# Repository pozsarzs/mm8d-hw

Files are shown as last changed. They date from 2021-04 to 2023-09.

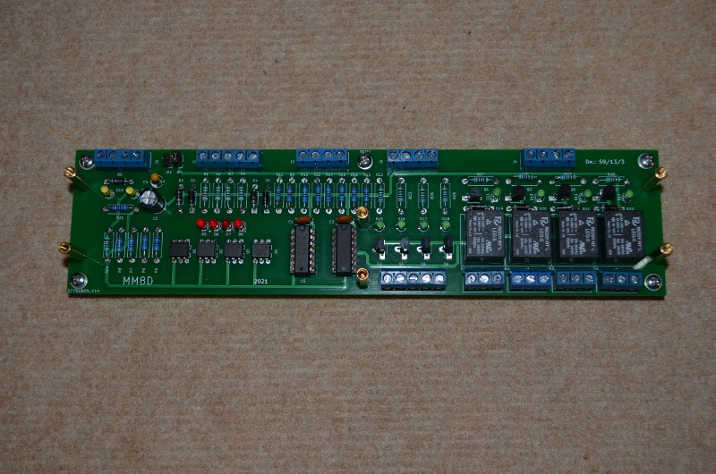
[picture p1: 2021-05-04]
pictures/mm8d.jpg

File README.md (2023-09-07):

**MM8D * Growing house and irrigation controlling and remote monitoring system**  
Copyright (C) 2020-2022 Pozsár Zsolt <pozsarzs@gmail.com>  
Homepage: <http://www.pozsarzs.hu>  
GitHub: <https://github.com/pozsarzs/mm8d-hw>

**Documentation**

- version:             2.0
- language:            en
- licence:             CC-BY-NC-4.0

**Hardware**

 - version:            v210326

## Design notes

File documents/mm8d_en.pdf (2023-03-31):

## MM8D Central controlling device

### Technical manual

Hardware version: v210326
MM8D software version: v0.3 Technical manual version: v2.0 Issue date: 2022.03.30.
Drawing number: 59/13/1
Titles: | MM8D Central controlling device | Rev.: 210326 Pages: | 1/26
| Technical manual
Name: Pozsár Zsolt | Date: | 2022.03.30.

Content

Titles: | MM8D Central controlling device | Rev.: 210326 Pages: | 2/26

## I. Hardware

Titles: | MM8D Central controlling device | Rev.: 210326 Pages: | 3/26

### 1. Technical data

Supply voltage: | 3.3/5 V DC SELV
Supply current: | max. 1 A
Isolation class: | Class 0
Mechanical size: | 240 x 60 x 25 mm
IP protection: | IP 00
Mass of cover: | termoplast (PC), only top cover

### 2. General description

The device consists of two parts: the control computer and the adapter card. The card can also be connected to 3.3V and 5V TTL systems. The control program is designed for PC and Raspberry Pi, the interface PC is connected to the LPT port, in the second case to the GPIO port. The adapter card has four 24V DC, galvanically isolated, polarity-protected inputs. Of the eight outputs, four are morse-contact relay outputs and four are open collector outputs for lower load (e.g., LED). The load capacity of the relay output is 5A (max. 240V AC or 100V DC), the load capacity of the open collector outputs is 80 mA (max. 24V DC).

### 3. Schematic and PCB drawings

The wiring diagrams of the device is shown in Annex 1, PCB drawings are in Annex 2-4. You can download it as part of the complete documentation or in separate PDF, SVG and KiCAD formats from the developer/manufacturer's website. The Gerber files needed for production are included in the package.

### 4. Other drawings and documents

Documentation package contents mechanical drawing of top cover.

### 5. Terms of use

Hardware documentation can be modified and/or redistributed under the Creativ Commons 4.0 Attribution Non-Commercial (CC-BY-NC-4.0) License. You can read the full text of the license online. (Refer to Chapter III for references.)

Titles: | MM8D Central controlling device | Rev.: 210326 Pages: | 4/26

### 6. Look of board

a) Manuals and connectors
1. LEDs of input #1-4
2. LEDs of relay output #1-4
3. LEDs of LED output #1-4
4. LEDs of power inputs
5. J1 connector - inputs
6. J2 connector - to computer
7. J3 connector - from power supply
8. J4 connector - from computer
9. J5 connector - from computer
10. J6 connector - contactors of relay output #1
11. J7 connector - contactors of relay output #2
12. J8 connector - contactors of relay output #3
13. J9 connector - contactors of relay output #4
14. J10 connector - LED outputs #1-4
15. Mounting holes
16. Jumpers

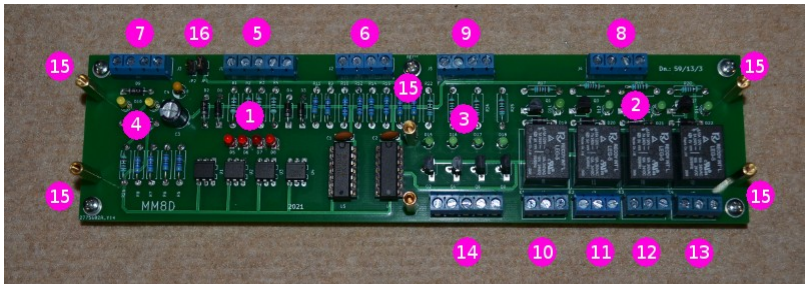
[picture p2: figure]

b) Jumpers
sign | function
for PC (LPT port) | for Rasperrry Pi (GPIO port)
JP1 | CLOSE | OPEN
JP2 | OPEN | CLOSE
Titles: | MM8D Central controlling device | Rev.: 210326 Pages: | 5/26

Figure 1: Manuals and connectors

c) Pinout of connectors
sign | pin | function | voltage level
J1 | 1 | input #1 | I1 | +24 V
| 2 | input #2 | I2 | +24 V
| 3 | input #3 | I3 | +24 V
| 4 | input #4 | I4 | +24 V
| 5 | common | ICOM
J2 | 1 | input #1 to computer | I1C | +3.3/5 V
| 2 | input #2 to computer | I2C | +3.3/5 V
| 3 | input #3 to computer | I3C | +3.3/5 V
| 4 | input #4 to computer | I4C | +3.3/5 V
J3 | 1 | power voltage input | +5 V | +5 V
| 2 | GND | GND
| 3 | GND | GND
| 4 | power voltage input | +3.3 V | +3.3 V
J4 | 1 | relay output #1 from computer | RO1C | +3.3/5 V
| 2 | relay output #2 from computer | RO2C | +3.3/5 V
| 3 | relay output #3 from computer | RO3C | +3.3/5 V
| 4 | relay output #4 from computer | RO4C | +3.3/5 V
J5 | 1 | LED output #1 from computer | LO1C | +3.3/5 V
| 2 | LED output #2 from computer | LO2C | +3.3/5 V
| 3 | LED output #3 from computer | LO3C | +3.3/5 V
| 4 | LED output #4 from computer | LO4C | +3.3/5 V
J6-9 | 1 | relay contactor NO | RO?NO
| 2 | relay contactor COM | RO?COM
| 3 | relay contactor NC | RO?NC
J10 | 1 | LED output #1 (open collector) | LO1
| 2 | LED output #2 (open collector) | LO2
| 3 | LED output #3 (open collector) | LO3
| 4 | LED output #4 (open collector) | LO4
| 5 | GND | GND
Titles: | MM8D Central controlling device | Rev.: 210326 Pages: | 6/26

d) Connect to computer
MM8D | Raspberry Pi | PC
sign | pin | function | sign | pin | function | sign | pin | function
J2 | 1 | I1C | | 3 | GPIO02 | LPT port | 15 | -ERROR
| 2 | I2C | | 5 | GPIO03 | | 13 | SELECT
| 3 | I3C | | 7 | GPIO04 | | 12 | PE
| 4 | I4C | | 11 | GPIO17 | | 10 | -ACK
J3 | 1 | +5 V | | 2 | +5 V | power supply | | +5 V
| 2 | GND | | 6 | GND | | | GND
| 3 | GND | | 9 | GND | LPT port | 25 | GND
| 4 | +3.3 V | | 17 | +3.3 V | | - | -
J4 | 1 | RO1C | | 12 | GPIO18 | | 2 | DO
| 2 | RO2C | | 16 | GPIO23 | | 3 | D1
| 3 | RO3C | | 18 | GPIO24 | | 4 | D2
| 4 | RO4C | | 22 | GPIO25 | | 5 | D3
J5 | 1 | LO1C | | 32 | GPIO12 | | 6 | D4
| 2 | LO2C | | 36 | GPIO16 | | 7 | D5
| 3 | LO3C | | 38 | GPIO20 | | 8 | D6
| 4 | LO4C | | 40 | GPIO21 | | 9 | D7

GPIO
port
e) Connect to environment
sign | pin | function | source/target
J1 | 1 | I1 | mains overcurrent breakers
| 2 | I2 | water pressure sensor (low pressure)
| 3 | I3 | water pressure sensor (high pressure)
| 4 | I4 | (unused)
| 5 | ICOM | common
J6 | 1-3 | RO1 | alarm output to alarm device
J7 | 1-3 | RO2 | valve control #1 of irrigator
J8 | 1-3 | RO3 | valve control #2 of irrigator
J9 | 1-3 | RO4 | valve control #3 of irrigator
J10 | 1 | LO1 | ACTIVE light (blue)
| 2 | LO2 | WARNING light (yellow)
| 3 | LO3 | ERROR light (red)
| 4 | LO4 | WATER PUMP ERROR light (red)
| 5 | GND | GND
Titles: | MM8D Central controlling device | Rev.: 210326 Pages: | 7/26

### 7. Downloadable documentation

The complete documentation of the hardware in the .tar.gz format compressed file can be downloaded from the manufacturer's website or Github. (Refer to Chapter III for references.) Name of package is: mm8d-hw-210326-2.0.tar.gz.

Content of package - only important files:

mm8d-hw
├───cad_files | KiCAD files
│ | mm8d.pro | project file
│ | mm8d.sch | schematic drawing
│ | mm8d.kicad_pcb | PCB drawing
│ | mm8d.drl | drilling file
│ | mm8d-*.gbr | Gerber files
├───documents | documentation
│ | mm8d_en.pdf | Technical manual
│ | pcb_*.pdf | pcb drawings
│ | sch_*.pdf | schematic drawings
├───pictures | pictures
│ | mm8d.jpg | look of the unit
│ | pcb_*.svg | PCB drawings
│ | sch_*.svg | schematic drawings
│
├───LICENCE | terms of use
└───README.md | short description
Titles: | MM8D Central controlling device | Rev.: 210326 Pages: | 8/26

## II. Software

Titles: | MM8D Central controlling device | Rev.: 210326 Pages: | 9/26

### 1. General description

The software consists of five main parts:

Operating daemon

The connected MM6D and MM7D electrical equipment is controlled by a Python program that runs as a service in the background. Utilities are Bash shell programs, configuration files are in text (INI) format. The configuration program has a full screen character interface, its source code (FreePascal) is only included in the tar.gz package. This part of the software is included in the tar.gz and mm8d-sw Debian packages.

Environmental characteristics adjustment program

The setup program has a full screen character interface, its source code (FreePascal) is included in the tar.gz package only. This part of the software is included in the tar.gz package and the mm8d-eec Debian package.

Web interface

Data access is provided by CGI programs written in Perl, its Bash shell utility, and web content consists of static HTML files. This requires an Apache2 web server. This part of the software is included in the tar.gz package and the mm8d-web Debian package.

Hardware checker program

This Python program can be used to verify that the hardware is working properly. Before testing running service of the software must be stopped. This part of the software is included in the tar.gz package and the mm8d-sw Debian package.

### 2. Prepare installation

Before installing the program, you need to install Raspbian OS Lite on your Raspberry Pi and Debian GNU/Linux on PC. Remember to change the default password for user pi, set the device name (hostname) and access to the local network. For easy remote access, use a permanent IP address or set up an IP address assignment on your router.

Prepare operation system:

user@localhost$ sudo apt-get update
user@localhost$ sudo apt-get upgrade
Titles: | MM8D Central controlling device | Rev.: 210326 Pages: | 10/26

user@localhost$ sudo apt-get install git wget
user@localhost$ sudo echo "deb http://www.szerafingomba.hu/deb/ ./" >> /etc/apt/sources.list
user@localhost$ sudo wget -q -O - http://www.szerafingomba.hu/deb/KEY.gpg | apt-key add -
user@localhost$ sudo apt-get update
user@localhost$ mkdir $HOME/download

### 3. Download

Download program from homepage:

user@localhost$ cd $HOME/download
user@localhost$ wget http://www.szerafingomba.hu/softwares/mm8d/mm8d-sw-0.3-armhf.tar.gz user@localhost$ tar -xzf mm8d-sw-0.3-armhf.tar.gz
(Note: on PC use amd64 or i386 instead armhf.)

Download latest version of program from Github:

user@localhost$ cd $HOME/download
user@localhost$ git clone http://github.com/pozsarzs/mm8d-sw.git

### 4. Installation

user@localhost$ cd mm8d-sw user@localhost$ ./prepare
user@localhost$ ./install

Download and install with package manager:

user@localhost$ sudo apt-get install mm8d-sw mm8d-web mm8d-eec

### 5. Files of program

The program's installed and runtime created files, with explanations of important files for the user and the purpose of symbolic links:

/
│
├───etc
│ | ├───cron.d
│ | │ | mm8d-sw
│ | │ | mm8d-web
│ | ├───init.d
│ | │ | mm8d.sh
│ | ├───rc0.d
│ | │ | K01mm8d.sh | » /etc/init.d/mm8d.sh
│ | ├───rc2.d
│ | │ | S01mm8d.sh | » /etc/init.d/mm8d.sh
│ | ├───rc3.d
│ | │ | S01mm8d.sh | » /etc/init.d/mm8d.sh
│ | ├───rc4.d
│ | │ | S01mm8d.sh | » /etc/init.d/mm8d.sh
│ | ├───rc5.d
│ | │ | S01mm8d.sh | » /etc/init.d/mm8d.sh
│ | ├───rc6.d
Titles: | MM8D Central controlling device | Rev.: 210326 Pages: | 11/26

│ | │ | K01mm8d.sh | » /etc/init.d/mm8d.sh
│ | ├───systemd
│ | │ | └───system
│ | │ | mm8d.service
│ | └───motd
├───usr
│ | ├───lib
│ | │ | └───cgi
│ | │ | getdata.cgi | CGI programs
│ | │ | getenvirconf.cgi
│ | │ | getpage.cgi
│ | └───local
│ | ├───bin
│ | │ | mm8d.py | daemon program
│ | │ | mm8d-creatediagrams | diagram creator
│ | │ | mm8d-editenvirconf | edit envir. characteristics
│ | │ | mm8d-editenvirconf.bin | settings editor
│ | │ | mm8d-editirrconf.bin | settings editor
│ | │ | mm8d-editmainconf | edit program settings
│ | │ | mm8d-editmainconf.bin | settings editor
│ | │ | mm8d-getsnapshots | camera picture downloader
│ | │ | mm8d-hwtest.py | hardware checker
│ | │ | mm8d-maintainlog | maintain log
│ | │ | mm8d-override | override outputs
│ | │ | mm8d-override.bin | override program
│ | │ | mm8d-startdaemon | start daemon
│ | │ | mm8d-statusofdaemon | show status of daemon
│ | │ | mm8d-stopdaemon | stop daemon
│ | │ | mm8d-updatestartpage | update startpage
│ | │ | mm8d-viewlog | show logfile
│ | │ | mm8d-webpage | show web interface
│ | ├───etc
│ | │ | └───mm8d
│ | │ | envir-ch?.ini | envir. characteristics settings
│ | │ | irrigator.ini | irrigator settings
│ | │ | mm8d.ini | program settings
│ | └───share
│ | ├───doc
│ | │ | └───mm8d
│ | │ | AUTHORS | author(s)
│ | │ | COPYING | terms of use (EN)
│ | │ | INSTALL.pc | installation instruction
│ | │ | INSTALL.raspi | installation instruction
│ | │ | README | information (EN)
│ | │ | VERSION | version
│ | │ | cgiprogs.txt | about CGI programs
│ | │ | changelog | log of changes
│ | │ | connecting.txt | about connecting device
│ | │ | copyright | copyright information
│ | │ | exitcodes.txt | about exit codes
│ | │ | logfiles.txt | about logfiles
│ | ├───locale
│ | │ | └───??
│ | │ | mm8d.msg | message files
│ | ├───man
│ | │ | ├───man1 | manual pages (EN)
│ | │ | │ mm8d-creatediagrams.1.gz
│ | │ | │ mm8d-editenvirconf.1.gz
│ | │ | │ mm8d-editmainconf.1.gz
│ | │ | │ mm8d-getsnapshots.1.gz
│ | │ | │ mm8d-hwtest.py.1.gz
│ | │ | │ mm8d-maintainlog.1.gz
Titles: | MM8D Central controlling device | Rev.: 210326 Pages: | 12/26

│ | │ | │ mm8d-override.1.gz
│ | │ | │ mm8d-startdaemon.1.gz
│ | │ | │ mm8d-statusofdaemon.1.gz
│ | │ | │ mm8d-stopdaemon.1.gz
│ | │ | │ mm8d-updatestartpage.1.gz
│ | │ | │ mm8d-viewlog.1.gz
│ | │ | │ mm8d-webpage.1.gz
│ | │ | ├───man7 | manual pages (EN)
│ | │ | │ getdata.cgi.7.gz
│ | │ | │ getenvirconf.cgi.7.gz
│ | │ | │ getpage.cgi.7.gz
│ | │ | └───man8 | manual pages (EN)
│ | │ | mm8d.py.8.gz
│ | └───mm8d
│ | footer_??.html
│ | header_??.html
└───var
├───local
│ | ├───lib
│ | │ | └───mm8d
│ | │ | └───?
│ | │ | out1
│ | │ | out2
│ | │ | out3
│ | │ | out4
│ | ├───lock
│ | │ | mm8d.lock
│ | │
│ | └───log
│ | mm8d-ch?.bak
│ | mm8d-ch?.log | log files
│ | debug-*.log | debug log
├───run
│ mm8d.pid
└───www
└───html
├───diagrams
│ | gasconcentrate-ch?.png
│ | humidity-ch?.png
│ | temperature-ch?.png
├───pics
│ | ants.jpg
│ | gasconcentrate-empty.png
│ | humidity-empty.png
│ | szerafin.ico
│ | temperature-empty.png
├───snapshots
│ | camera-ch?.jpg
styles.css
index.html
When installing with package manager, the program is installed to /usr instead of /usr/local.

### 6. Setup

Both configuration shell programs will stop the running service of MM8D, then open the editor and then start them after closing.
To set the program:

user@locahost$ mm8d-editmainconf

Titles: | MM8D Central controlling device | Rev.: 210326 Pages: | 13/26

To set the environmental characteristic and irrigator settings:

user@locahost$ mm8d-editenvirconf

### 7. Using the device

The device operates automatically after installation and setup and does not require any human intervention. The status of the growing site can be checked with a web browser, and settings can be made by logging via LAN with SSH client.

### 8. Terms of use

These programs are free softwares: you can redistribute they and/or modify they under the terms of the European Union Public License 1.1 version.

These programs are distributed in the hope that they will be useful, but WITHOUT ANY WARRANTY; without even the implied warranty of MERCHANTABILITY or FITNESS FOR A PARTICULAR PURPOSE. You can read the full text of the license online. (Refer to Chapter III for references.)

### 9. Screenshots

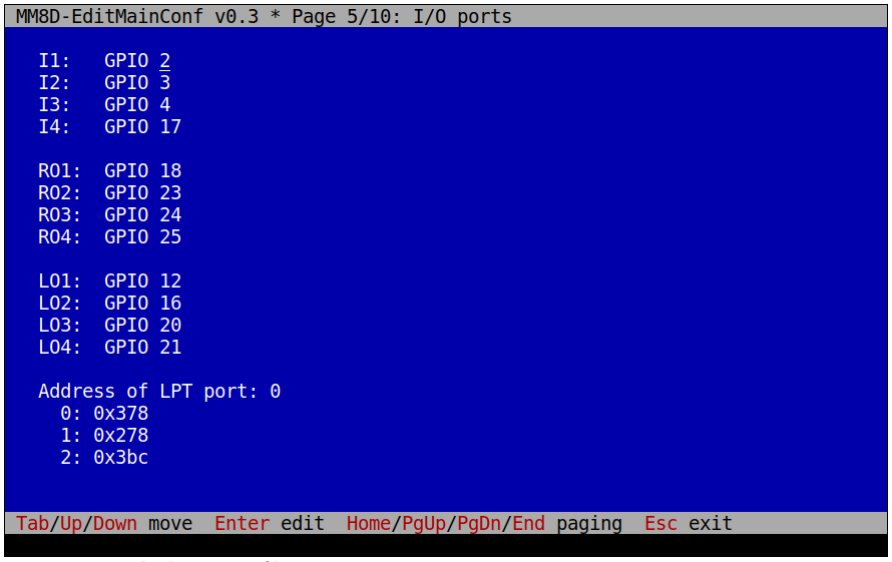
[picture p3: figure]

Titles: | MM8D Central controlling device | Rev.: 210326 Pages: | 14/26

Figure 2: mm8d-editmainconf.bin

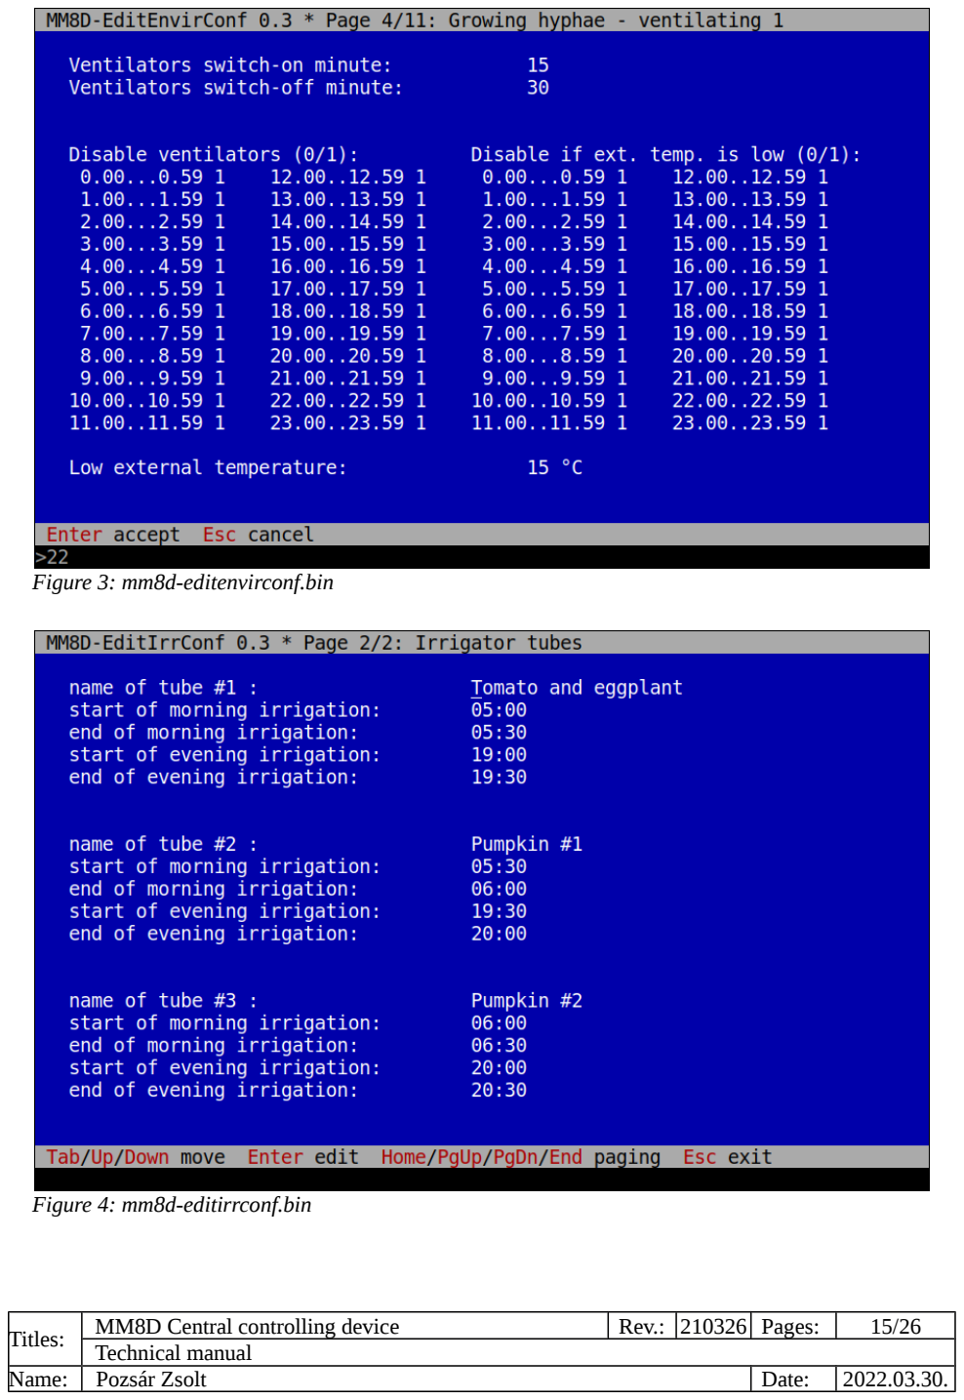
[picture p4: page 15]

Titles: | MM8D Central controlling device | Rev.: 210326 Pages: | 15/26

Figure 3: mm8d-editenvirconf.bin

Figure 4: mm8d-editirrconf.bin

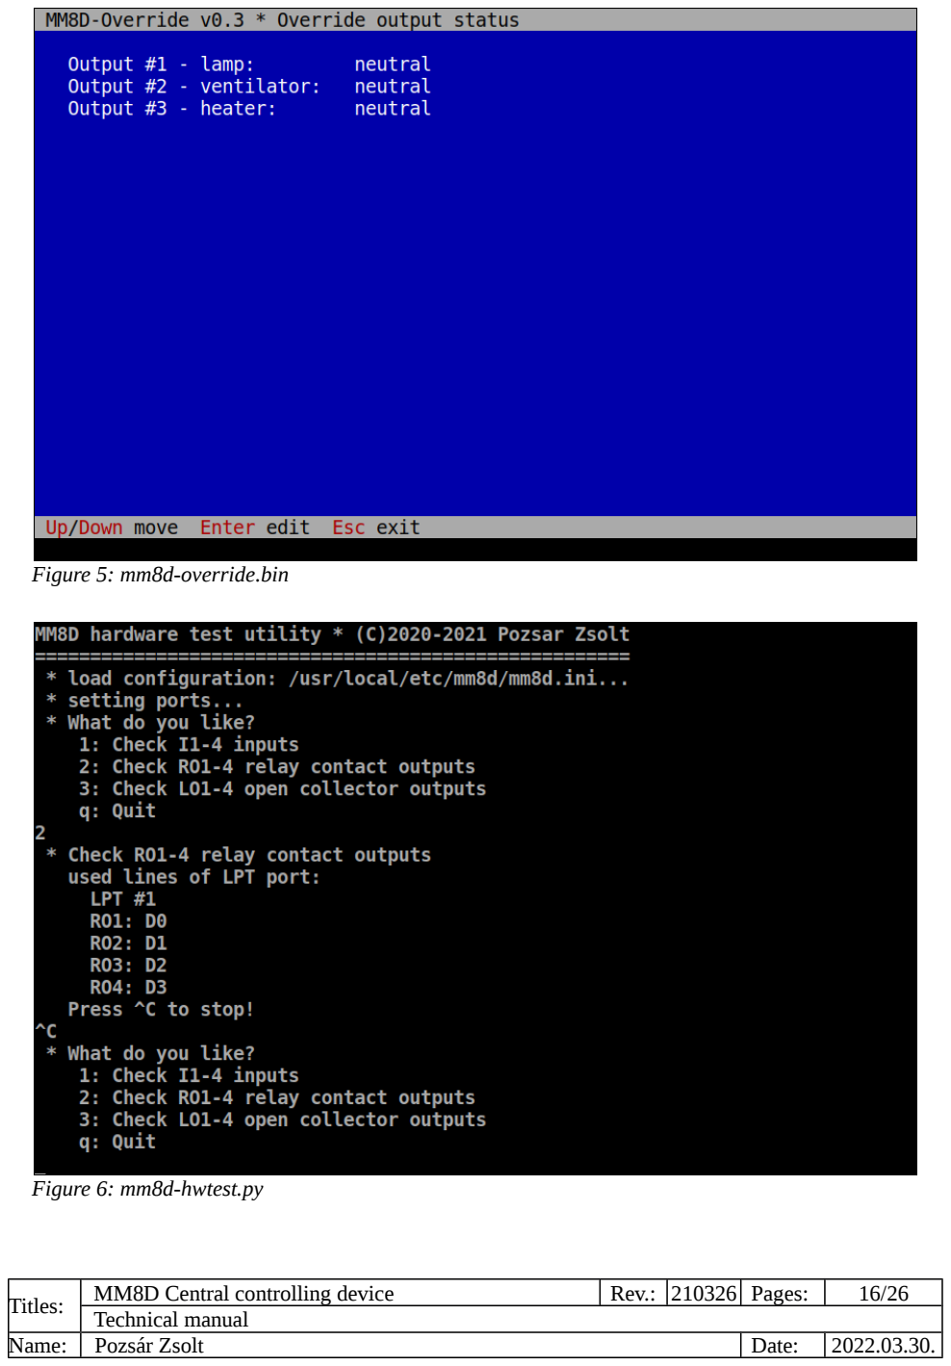
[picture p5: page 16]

Titles: | MM8D Central controlling device | Rev.: 210326 Pages: | 16/26

Figure 5: mm8d-override.bin

Figure 6: mm8d-hwtest.py

### 10. Downloadable software package

The software package in .tar.gz format compressed file can be downloaded from the manufacturer's website or Github. (Refer to Chapter III for references.)

Name of package are:mm8d-sw-0.3-amd64.tar.gz, mm8d-sw-0.3-armhf.tar.gz and mm8d-sw-0.3-i386.tar.gz.

Content of package - only important files:

mm8d-sw
│
├───binary | binary files
├───documents | documentation (EN)
│ | AUTHORS | author(s)
│ | INSTALL.pc | installation instruction
│ | INSTALL.raspi | installation instruction
│ | README | information
│ | VERSION | version number
│ | cgiprogs.txt | about CGI programs
│ | changelog | log of changes
│ | connecting.txt | about connecting device
│ | copyright | copyright information
│ | exitcodes.txt | about exit codes
│ | logfiles.txt | about logfiles
├───manuals | manual pages (EN)
├───messages | translated webpage text
├───packaging | files for make deb packages
├───programs | main programs (Python)
├───scripts | utility programs (Bash)
├───settings | configuration files
├───source | source code
├───webpage | static | components of webpage
├───install | installer script
├───prepare | system preparer script
├───uninstall | uninstaller script
├───LICENCE | terms of use (EN)
└───README.md | short description (EN)
Titles: | MM8D Central controlling device | Rev.: 210326 Pages: | 17/26

## III. Related links

Titles: | MM8D Central controlling device | Rev.: 210326 Pages: | 18/26

### 1. Hardware

Full package | http://www.szerafingomba.hu/equipments/mm8d/mm8d-hw-210326-2.0.tar.gz

Download from Github https://github.com/pozsarzs/mm8d-hw.git

Technical manual http://www.szerafingomba.hu/equipments/mm8d/technical-manual-210326-0.3-2.0-en.pdf

Schematic and PCB drawings (PDF):

Schematics | http://www.szerafingomba.hu/equipments/mm8d/sch_mm8d.pdf
PCB solder side | http://www.szerafingomba.hu/equipments/mm8d/pcb_mm8d-sold.pdf
PCB component side | http://www.szerafingomba.hu/equipments/mm8d/pcb_mm8d-comp.pdf
PCB silkscreen | http://www.szerafingomba.hu/equipments/mm8d/pcb_mm8d-silk.pdf

### 2. Software

for Raspberry Pi | http://www.szerafingomba.hu/softwares/mm8d/mm8d-sw-0.3-armhf.tar.gz
for AMD64 PC | http://www.szerafingomba.hu/softwares/mm8d/mm8d-sw-0.3-amd64.tar.gz
for i586 PC | http://www.szerafingomba.hu/softwares/mm8d/mm8d-sw-0.3-i586.tar.gz

Download from Github https://github.com/pozsarzs/mm8d-sw.git

### 3. Terms of use

CC-BY-NC-4.0 | https://creativecommons.org/licenses/by-nc/4.0/legalcode
CC-BY-NC-4.0 | https://creativecommons.org/licenses/by-nc/4.0/
EUPL v1.2 | https://eupl.eu/1.2/en/
GNU GPL v3.0 | https://www.gnu.org/licenses/gpl-3.0.html

### 4. Developer and manufacturer

Homepage | http://www.szerafingomba.hu
E-mail | info@szerafingomba.hu
Titles: | MM8D Central controlling device | Rev.: 210326 Pages: | 19/26

## IV. Annexes

Titles: | MM8D Central controlling device | Rev.: 210326 Pages: | 20/26

Content

1. Schematic of printed circuit board
2. PCB solder side
3. PCB component side
4. PCB silkscren
Titles: | MM8D Central controlling device | Rev.: 210326 Pages: | 21/26

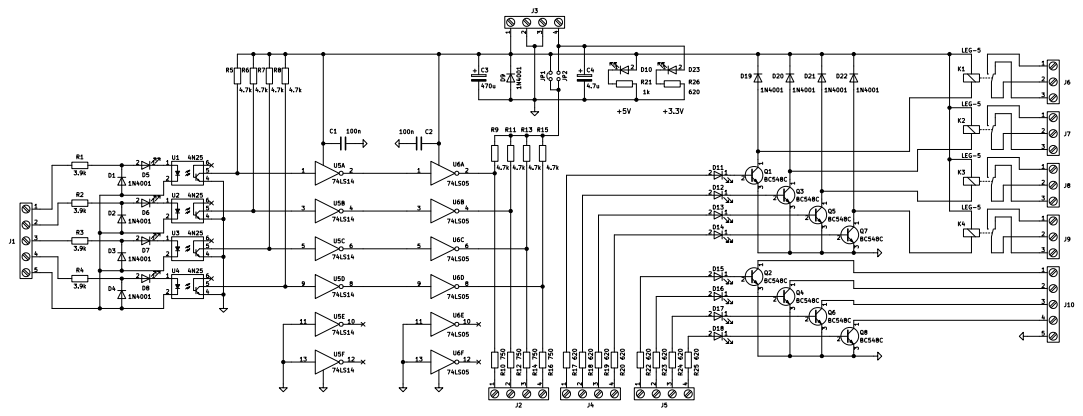
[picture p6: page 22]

Annex 1: Schematic of printed circuit board

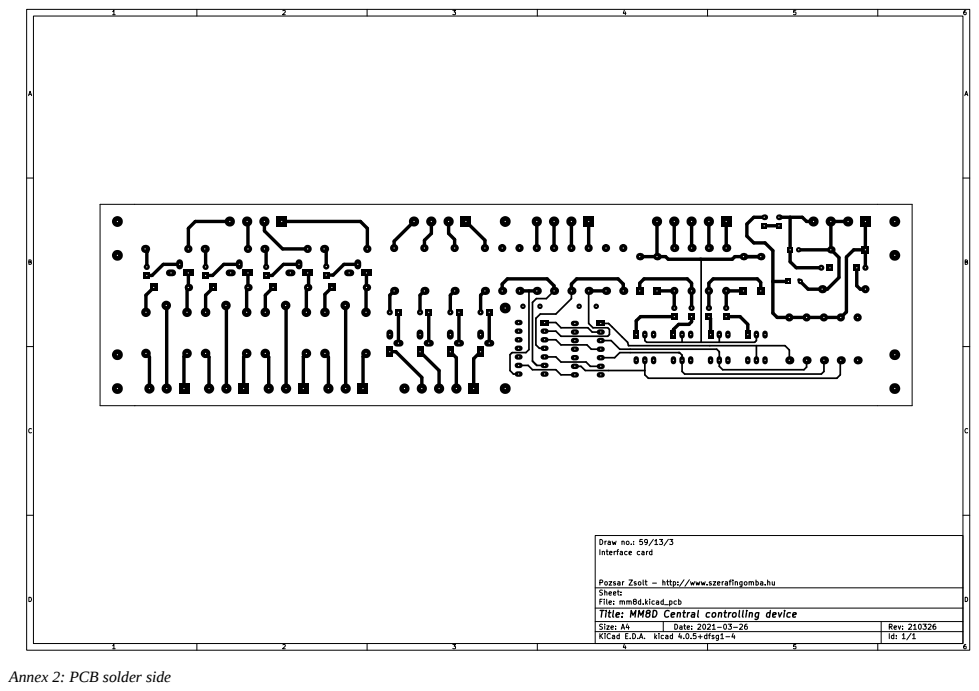
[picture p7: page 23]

Annex 2: PCB solder side

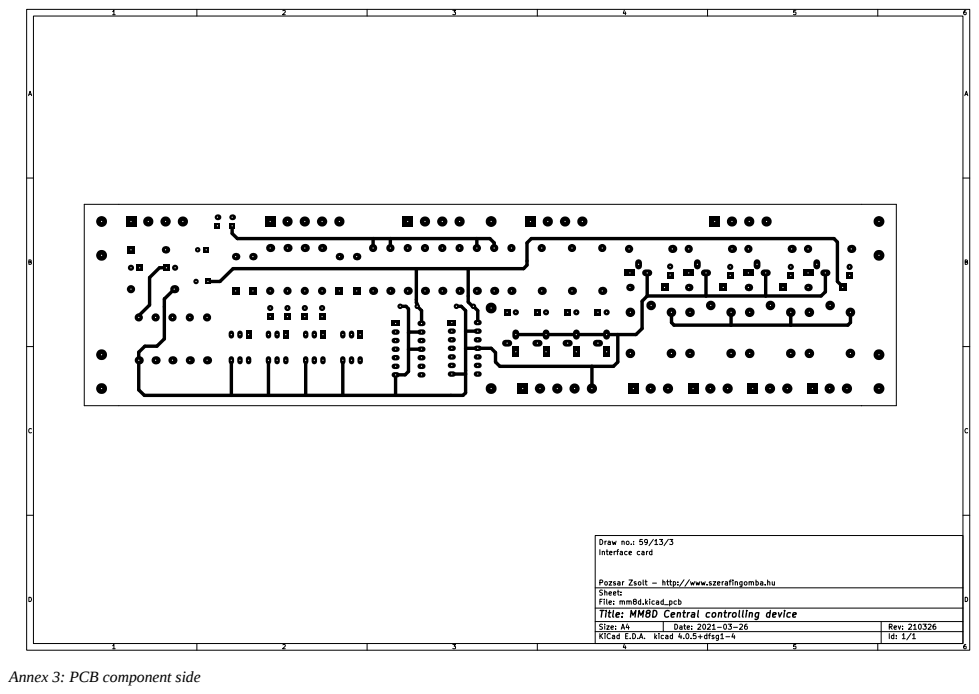
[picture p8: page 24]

Annex 3: PCB component side

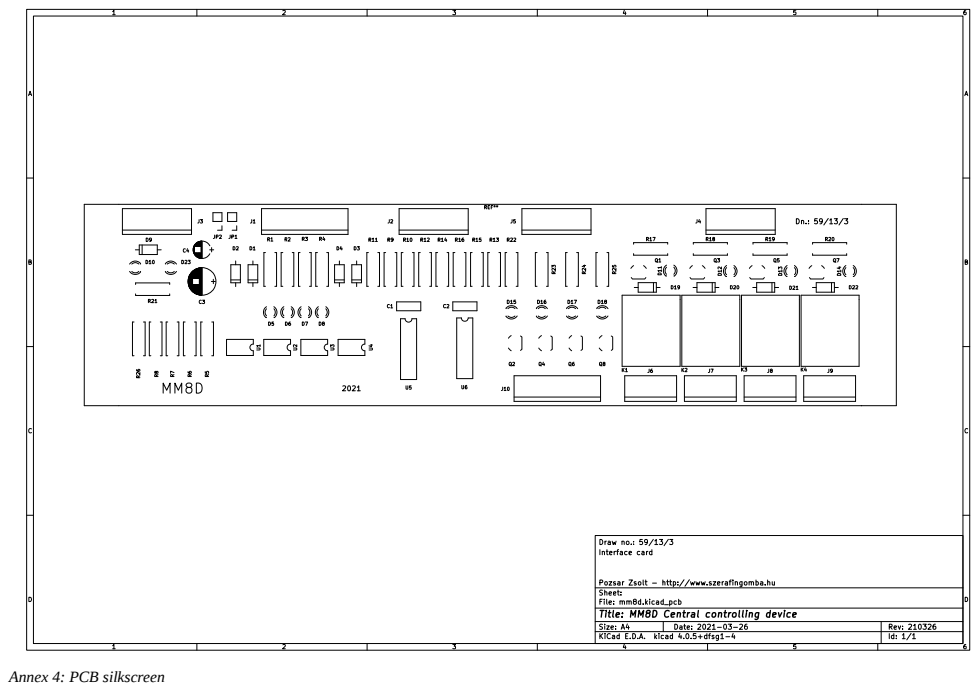
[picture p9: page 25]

Annex 4: PCB silkscreen

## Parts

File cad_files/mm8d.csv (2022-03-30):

Source | /home/pozsarzs/Dev/mm8d-hw/cad_files/mm8d.sch
Kicad Rev | Eeschema 4.0.5+dfsg1-4
Generated Date | 2021. ápr. 4. | vasárnap | 06:52:16 CEST
Title | MM8D Central controlling and remote monitoring device
Company | Pozsar Zsolt - http://www.szerafingomba.hu
Revision | 210326
Date Issue | 2021-03-26
Comment | Interface card
Comment | Draw no.: 59/13/2
Reference | Value | Library | Library Ref
J1 | Screw_Terminal_1x05 | conn | Screw_Terminal_1x05
R1 | 3.9k | device | R
D1 | 1N4001 | device | D
U1 | 4N25 | opto | 4N25
U2 | 4N25 | opto | 4N25
U3 | 4N25 | opto | 4N25
U4 | 4N25 | opto | 4N25
R5 | 4.7k | device | R
R6 | 4.7k | device | R
R7 | 4.7k | device | R
R8 | 4.7k | device | R
J3 | Screw_Terminal_1x04 | conn | Screw_Terminal_1x04
J2 | Screw_Terminal_1x04 | conn | Screw_Terminal_1x04
J10 | Screw_Terminal_1x05 | conn | Screw_Terminal_1x05
J7 | Screw_Terminal_1x03 | conn | Screw_Terminal_1x03
J9 | Screw_Terminal_1x03 | conn | Screw_Terminal_1x03
J8 | Screw_Terminal_1x03 | conn | Screw_Terminal_1x03
J4 | Screw_Terminal_1x04 | conn | Screw_Terminal_1x04
J5 | Screw_Terminal_1x04 | conn | Screw_Terminal_1x04
R17 | 620 | device | R
Q7 | BC548C | device | Q_NPN_CBE
Q5 | BC548C | device | Q_NPN_CBE
Q3 | BC548C | device | Q_NPN_CBE
Q1 | BC548C | device | Q_NPN_CBE
D19 | 1N4001 | device | D
J6 | Screw_Terminal_1x03 | conn | Screw_Terminal_1x03
K1 | LEG-5 | relay_leg-5 | Relay_LEG-5
K2 | LEG-5 | relay_leg-5 | Relay_LEG-5
K3 | LEG-5 | relay_leg-5 | Relay_LEG-5
K4 | LEG-5 | relay_leg-5 | Relay_LEG-5
D5 | LED | device | LED
D6 | LED | device | LED
D7 | LED | device | LED
D8 | LED | device | LED
U5 | 74LS14 | 74xx | 74LS14
U6 | 74LS05 | 74xx | 74LS05
D11 | LED | device | LED
D12 | LED | device | LED
D13 | LED | device | LED
D14 | LED | device | LED
JP1 | Jumper_NC_Small | device | Jumper_NC_Small
JP2 | Jumper_NO_Small | device | Jumper_NO_Small
C2 | 100n | device | C
C1 | 100n | device | C
C3 | 470u | device | CP
D10 | LED | device | LED
R21 | 1k | device | R
C4 | 4.7u | device | CP
D9 | 1N4001 | device | D
R2 | 3.9k | device | R
R3 | 3.9k | device | R
R4 | 3.9k | device | R
D2 | 1N4001 | device | D
D4 | 1N4001 | device | D
D3 | 1N4001 | device | D
D20 | 1N4001 | device | D
D21 | 1N4001 | device | D
D22 | 1N4001 | device | D
Q2 | BC548C | device | Q_NPN_CBE
Q4 | BC548C | device | Q_NPN_CBE
Q6 | BC548C | device | Q_NPN_CBE
Q8 | BC548C | device | Q_NPN_CBE
D15 | LED | device | LED
D16 | LED | device | LED
D17 | LED | device | LED
D18 | LED | device | LED
R9 | 4.7k | device | R
R11 | 4.7k | device | R
R13 | 4.7k | device | R
R15 | 4.7k | device | R
R18 | 620 | device | R
R19 | 620 | device | R
R20 | 620 | device | R
R22 | 620 | device | R
R23 | 620 | device | R
R24 | 620 | device | R
R25 | 620 | device | R
R10 | 750 | device | R
R12 | 750 | device | R
R14 | 750 | device | R
R16 | 750 | device | R
D23 | LED | device | LED
R26 | 620 | device | R

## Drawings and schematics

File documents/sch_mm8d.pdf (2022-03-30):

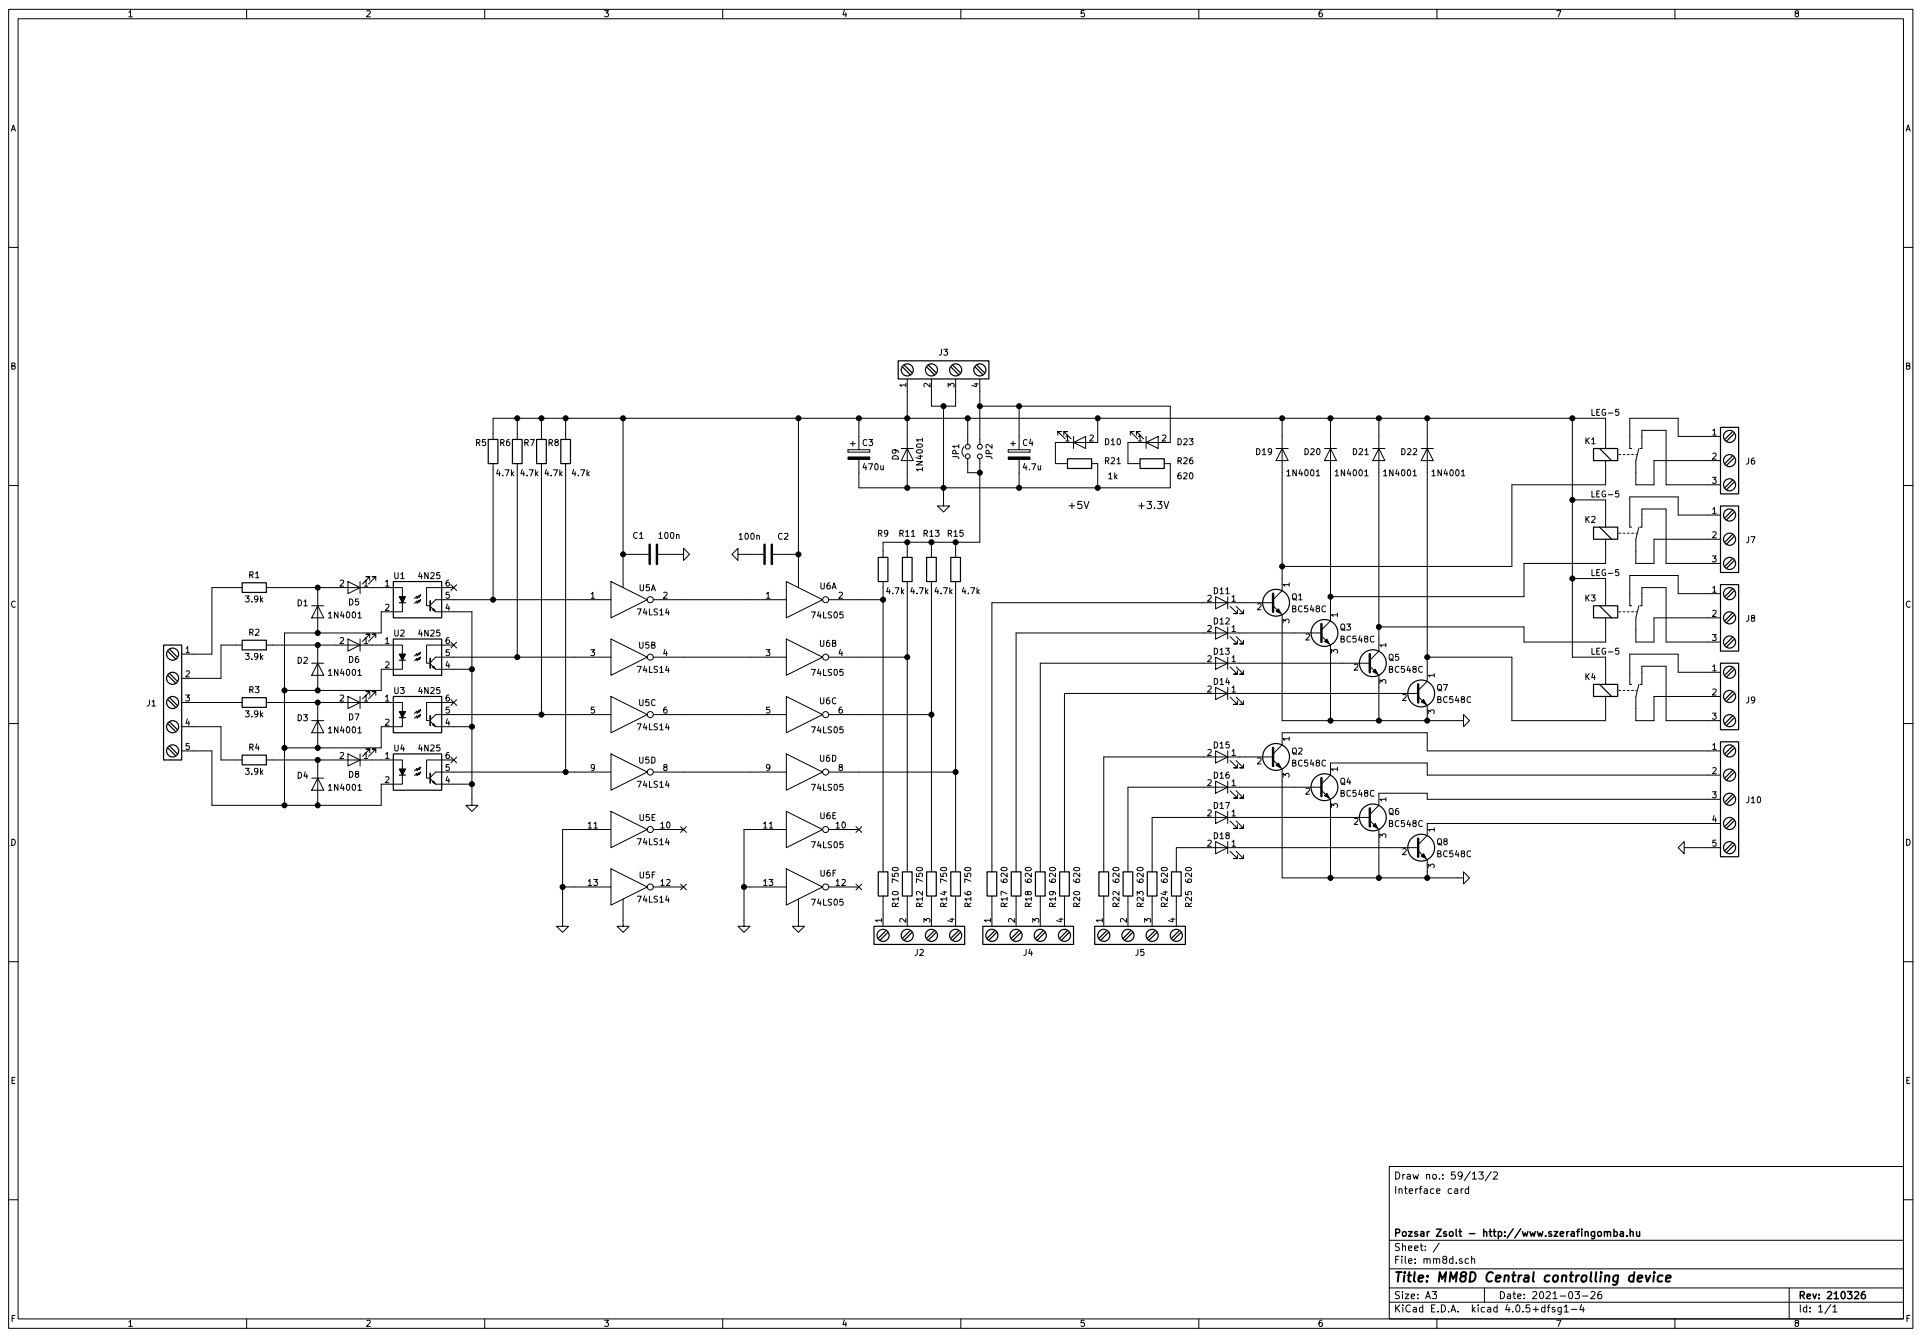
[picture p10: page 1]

Interface card Draw no.: 59/13/2

File: mm8d.sch Sheet: / Pozsar Zsolt - http://www.szerafingomba.hu

Id: 1/1 Title: MM8D Central controlling device

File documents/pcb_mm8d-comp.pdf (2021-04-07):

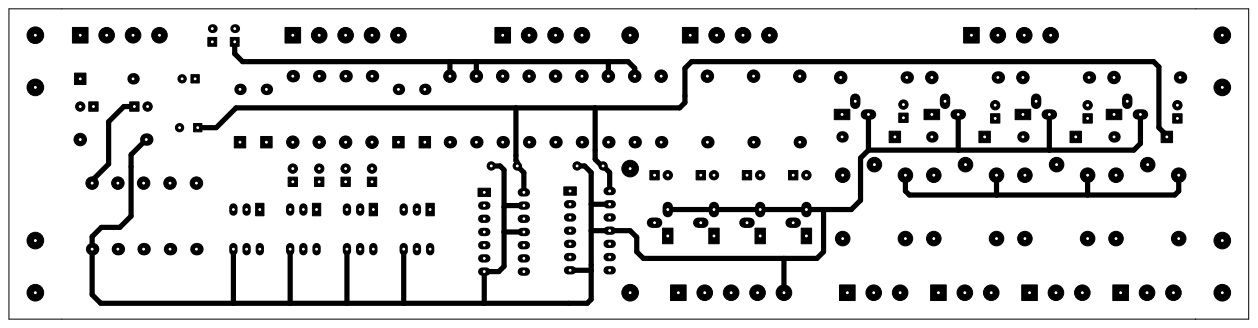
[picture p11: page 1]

Interface card Draw no.: 59/13/3

File: mm8d.kicad_pcb Sheet: Pozsar Zsolt - http://www.szerafingomba.hu

Id: 1/1 Title: MM8D Central controlling device

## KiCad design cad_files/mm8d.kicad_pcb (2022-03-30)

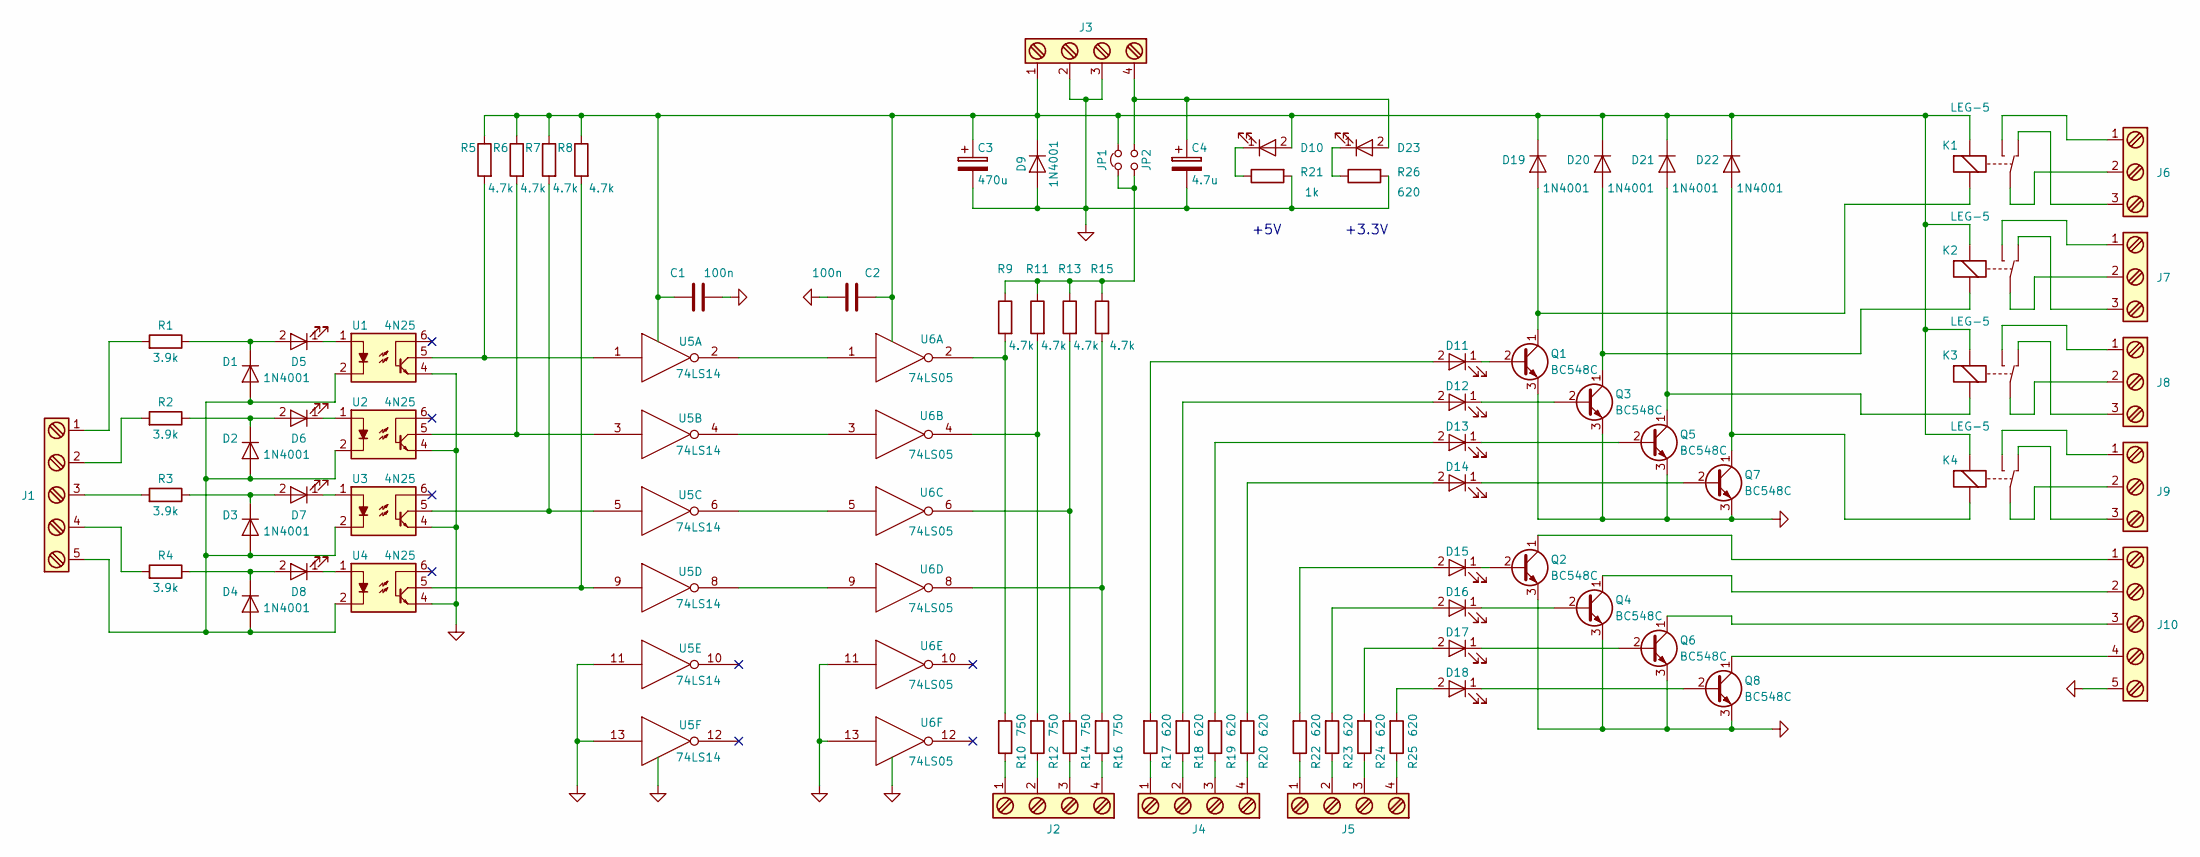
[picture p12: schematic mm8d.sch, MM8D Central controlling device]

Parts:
C1, C2: 100n; C_Rect_L7.0mm_W2.5mm_P5.00mm
C3: 470u; CP_Radial_D8.0mm_P3.50mm
C4: 4.7u; CP_Radial_D5.0mm_P2.50mm
D1, D2, D3, D4, D9, D19, D20, D21, D22: 1N4001; D_DO-41_SOD81_P10.16mm_Horizontal
D5, D6, D7, D8, D10, D11, D12, D13, D14, D15, D16, D17, D18, D23: LED; LED_D3.0mm
J1, J10: Screw_Terminal_1x05; bornier5
J2, J3, J4, J5: Screw_Terminal_1x04; bornier4
J6, J7, J8, J9: Screw_Terminal_1x03; bornier3
JP1: Jumper_NC_Small; Socket_Strip_Straight_1x02_Pitch2.54mm
JP2: Jumper_NO_Small; Socket_Strip_Straight_1x02_Pitch2.54mm
K1, K2, K3, K4: LEG-5; relay_leg
Q1, Q2, Q3, Q4, Q5, Q6, Q7, Q8: BC548C; TO-92_Rugged
R1, R2, R3, R4: 3.9k; R_Axial_DIN0411_L9.9mm_D3.6mm_P12.70mm_Horizontal
R5, R6, R7, R8, R9, R11, R13, R15: 4.7k; R_Axial_DIN0411_L9.9mm_D3.6mm_P12.70mm_Horizontal
R10, R12, R14, R16: 750; R_Axial_DIN0411_L9.9mm_D3.6mm_P12.70mm_Horizontal
R17, R18, R19, R20, R22, R23, R24, R25, R26: 620; R_Axial_DIN0411_L9.9mm_D3.6mm_P12.70mm_Horizontal
R21: 1k; R_Axial_DIN0411_L9.9mm_D3.6mm_P12.70mm_Horizontal
U1, U2, U3, U4: 4N25; DIP-6_W7.62mm_LongPads
U5: 74LS14; DIP-14_W7.62mm_LongPads
U6: 74LS05; DIP-14_W7.62mm_LongPads

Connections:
GND: C1.2, C2.2, C3.2, C4.2, D9.2 (A), J3.2, J3.3, J10.5, Q1.3 (E), Q2.3 (E), Q3.3 (E), Q4.3 (E), Q5.3 (E), Q6.3 (E), Q7.3 (E), Q8.3 (E), R21.2, R26.2, U1.4, U2.4, U3.4, U4.4, U5.7 (GND), U5.11, U5.13, U6.7 (GND), U6.11, U6.13
unnamed: C4.1, D23.2 (A), J3.4, JP2.2
unnamed: D1.1 (K), D5.2 (A), R1.1
unnamed: D1.2 (A), D2.2 (A), D3.2 (A), D4.2 (A), J1.5, U1.2, U2.2, U3.2, U4.2
unnamed: D2.1 (K), D6.2 (A), R2.1
unnamed: D3.1 (K), D7.2 (A), R3.1
unnamed: D4.1 (K), D8.2 (A), R4.1
unnamed: D5.1 (K), U1.1
unnamed: D6.1 (K), U2.1
unnamed: D7.1 (K), U3.1
unnamed: D8.1 (K), U4.1
unnamed: D10.1 (K), R21.1
unnamed: D11.1 (K), Q1.2 (B)
unnamed: D11.2 (A), R17.2
unnamed: D12.1 (K), Q3.2 (B)
unnamed: D12.2 (A), R18.2
unnamed: D13.1 (K), Q5.2 (B)
unnamed: D13.2 (A), R19.2
unnamed: D14.1 (K), Q7.2 (B)
unnamed: D14.2 (A), R20.2
unnamed: D15.1 (K), Q2.2 (B)
unnamed: D15.2 (A), R22.2
unnamed: D16.1 (K), Q4.2 (B)
unnamed: D16.2 (A), R23.2
unnamed: D17.1 (K), Q6.2 (B)
unnamed: D17.2 (A), R24.2
unnamed: D18.1 (K), Q8.2 (B)
unnamed: D18.2 (A), R25.2
unnamed: D19.2 (A), K1.2 (Coil), Q1.1 (C)
unnamed: D20.2 (A), K2.2 (Coil), Q3.1 (C)
unnamed: D21.2 (A), K3.2 (Coil), Q5.1 (C)
unnamed: D22.2 (A), K4.2 (Coil), Q7.1 (C)
unnamed: D23.1 (K), R26.1
unnamed: J1.1, R1.2
unnamed: J1.2, R2.2
unnamed: J1.3, R3.2
unnamed: J1.4, R4.2
unnamed: J2.1, R10.1
unnamed: J2.2, R12.1
unnamed: J2.3, R14.1
unnamed: J2.4, R16.1
unnamed: J4.1, R17.1
unnamed: J4.2, R18.1
unnamed: J4.3, R19.1
unnamed: J4.4, R20.1
unnamed: J5.1, R22.1
unnamed: J5.2, R23.1
unnamed: J5.3, R24.1
unnamed: J5.4, R25.1
unnamed: J6.1, K1.5 (NO)
unnamed: J6.2, K1.3 (Common)
unnamed: J6.3, K1.4 (NC)
unnamed: J7.1, K2.5 (NO)
unnamed: J7.2, K2.3 (Common)
unnamed: J7.3, K2.4 (NC)
unnamed: J8.1, K3.5 (NO)
unnamed: J8.2, K3.3 (Common)
unnamed: J8.3, K3.4 (NC)
unnamed: J9.1, K4.5 (NO)
unnamed: J9.2, K4.3 (Common)
unnamed: J9.3, K4.4 (NC)
unnamed: J10.1, Q2.1 (C)
unnamed: J10.2, Q4.1 (C)
unnamed: J10.3, Q6.1 (C)
unnamed: J10.4, Q8.1 (C)
unnamed: JP1.1, JP2.1, R9.1, R11.1, R13.1, R15.1
unnamed: R5.2, U1.5, U5.1
unnamed: R6.2, U2.5, U5.3
unnamed: R7.2, U3.5, U5.5
unnamed: R8.2, U4.5, U5.9
unnamed: R9.2, R10.2, U6.2
unnamed: R11.2, R12.2, U6.4
unnamed: R13.2, R14.2, U6.6
unnamed: R15.2, R16.2, U6.8
unnamed: U5.2, U6.1
unnamed: U5.4, U6.3
unnamed: U5.6, U6.5
unnamed: U5.8, U6.9
VCC: C1.1, C2.1, C3.1, D9.1 (K), D10.2 (A), D19.1 (K), D20.1 (K), D21.1 (K), D22.1 (K), J3.1, JP1.2, K1.1 (Coil), K2.1 (Coil), K3.1 (Coil), K4.1 (Coil), R5.1, R6.1, R7.1, R8.1, U5.14 (VCC), U6.14 (VCC)

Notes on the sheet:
+5V
+3.3V

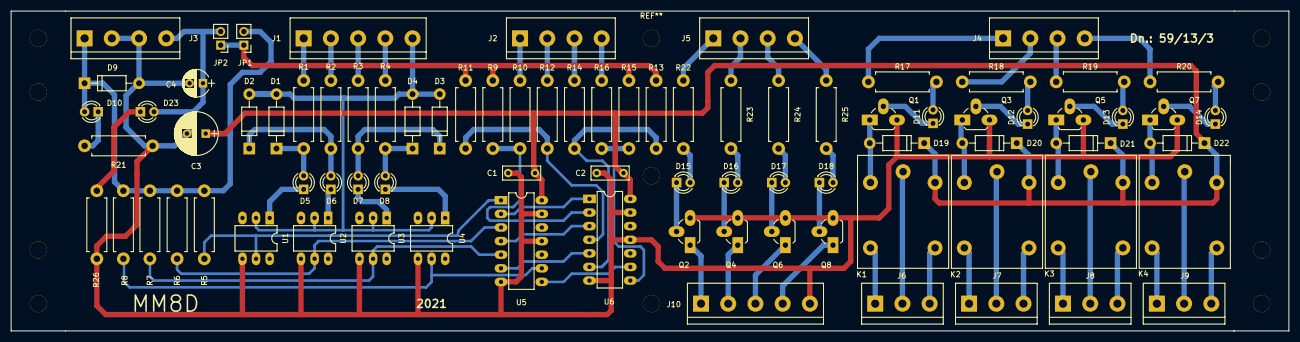
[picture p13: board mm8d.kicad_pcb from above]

Board: 2 copper layers, 238.5 x 59.7 mm, 83 parts (0 on the bottom side), 79 nets.
